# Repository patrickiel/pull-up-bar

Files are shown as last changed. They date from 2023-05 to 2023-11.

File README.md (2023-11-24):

# Pull-up bar

## The idea
An ergonomic pull-up bar for ceiling mounting, which works well in combination with gymnastic rings.

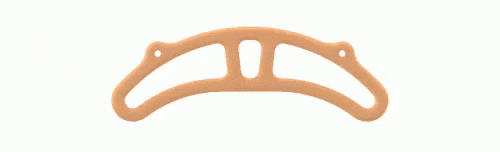
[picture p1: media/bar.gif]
Pullup Bar animation


## Why not buy one?
I decided to build my own pull-up bar because I was not satisfied with the commercially available ceiling mounted pull-up bars. I had the following requirements:
- Ergonomics: Everyone's body is unique. I wanted to create a pull-up bar that fits my body, and yours. You can find a custom drawing that fits your body shape below in the instructions.
- Dismountable: After the workout, the bar should be easy to remove.
- Adjustable grip positions: Narrow, medium and wide grip.
- Resistance Band Friendly: There should be a place to attach a resistance band.
- Minimal damage: Living in a rental apartment, I wanted to minimize damage to the ceiling. The unit hat to be able to mount on the same hooks as the gymnastic rings, which typically have a standard spacing of 50 cm.

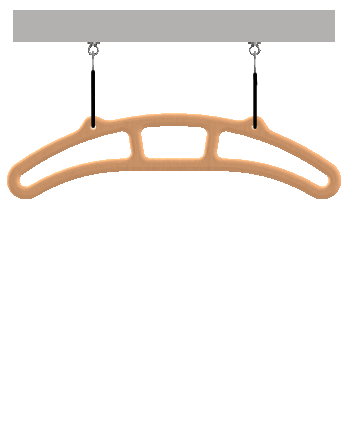
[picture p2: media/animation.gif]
Pull-up bar and rings


## Biacromial breadth
Based on this study https://pubmed.ncbi.nlm.nih.gov/24662157/, the optimal grip width is 1-2 times the biacromial breadth. A medium grip (1.5 times the biacromial width) may have some minor advantages over small and wide grips. This pull-up bar is designed to allow ony grips within this range.

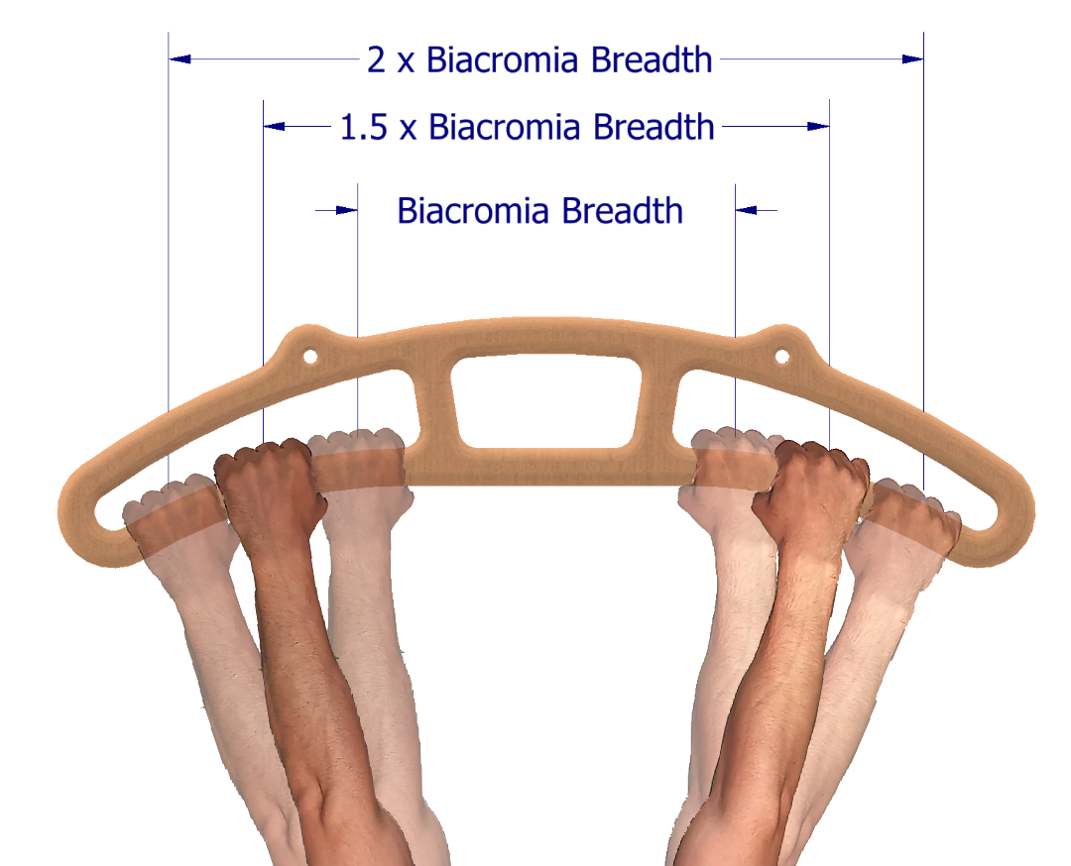
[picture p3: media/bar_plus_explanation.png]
Pull-up bar


# Build instructions

## Choose the plan
Measure your biacromial breadth (search for an online instruction) and choose the corresponding PDF-file [pull-up bar variants](cad/pull-up%20bar%20variants) 

## Tools
- Jigsaw
- Router
- Drill
- Sandpaper
- Tape Measure

## Materials
- Plywood
- Mounting materials (shackles or rope, hooks, carabiners)

## Build it
- If you're using a standard printer, use the tiling feature of your preferred PDF reader to print the second sheet of the PDF on several smaller sheets. Align these using the marks.
- Transfer the outline to the plywood and cut it out.
- Use your router to mill the edges, then sand.
- Mount it to your ceiling.
  
Final build

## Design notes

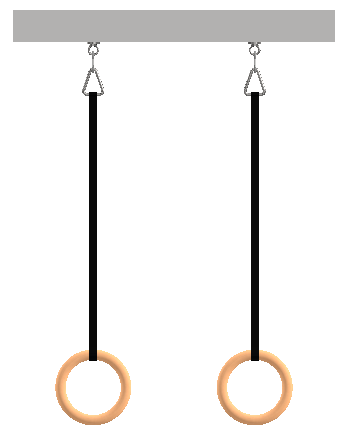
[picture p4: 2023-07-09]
media/animation_2.png

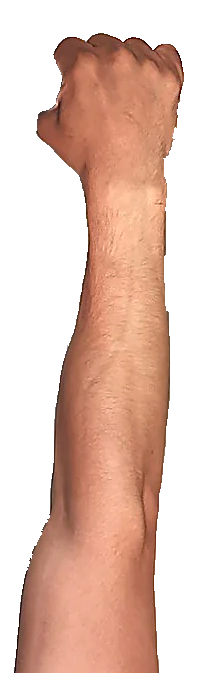
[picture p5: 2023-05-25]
media/right arm.png

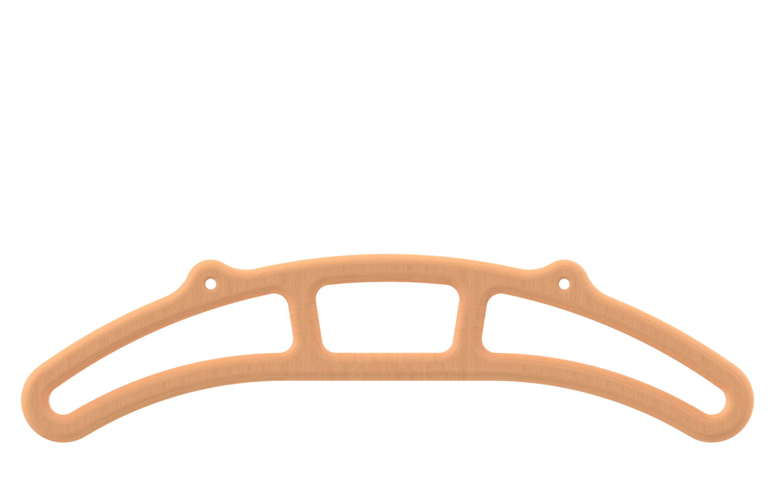
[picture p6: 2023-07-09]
media/bar.png

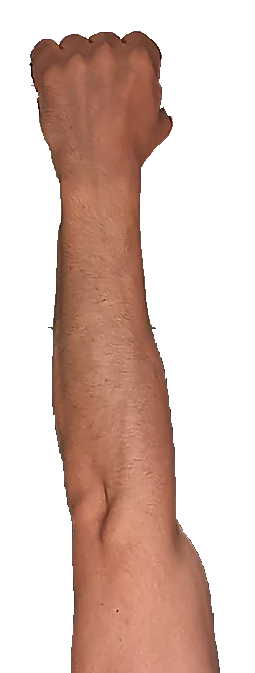
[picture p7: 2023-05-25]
media/left arm.png

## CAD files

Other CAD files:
cad/ISO 4017 - M8 x 50 - ISO.ipt
cad/bar.idw
cad/bar.ipt
cad/carabiner.ipt
cad/ceiling.ipt
cad/ground.ipt
cad/hook.ipt
cad/main.iam
cad/pull-up bar variants/biacromia breadth 25 cm (9.8 inch).idw
cad/pull-up bar variants/biacromia breadth 25 cm (9.8 inch).ipt
cad/pull-up bar variants/biacromia breadth 26 cm (10.2 inch).idw
cad/pull-up bar variants/biacromia breadth 26 cm (10.2 inch).ipt
cad/pull-up bar variants/biacromia breadth 27 cm (10.6 inch).idw
cad/pull-up bar variants/biacromia breadth 27 cm (10.6 inch).ipt
cad/pull-up bar variants/biacromia breadth 28 cm (11 inch).idw
cad/pull-up bar variants/biacromia breadth 28 cm (11 inch).ipt
cad/pull-up bar variants/biacromia breadth 29 cm (11.4 inch).idw
cad/pull-up bar variants/biacromia breadth 29 cm (11.4 inch).ipt
cad/pull-up bar variants/biacromia breadth 30 cm (11.8 inch).idw
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

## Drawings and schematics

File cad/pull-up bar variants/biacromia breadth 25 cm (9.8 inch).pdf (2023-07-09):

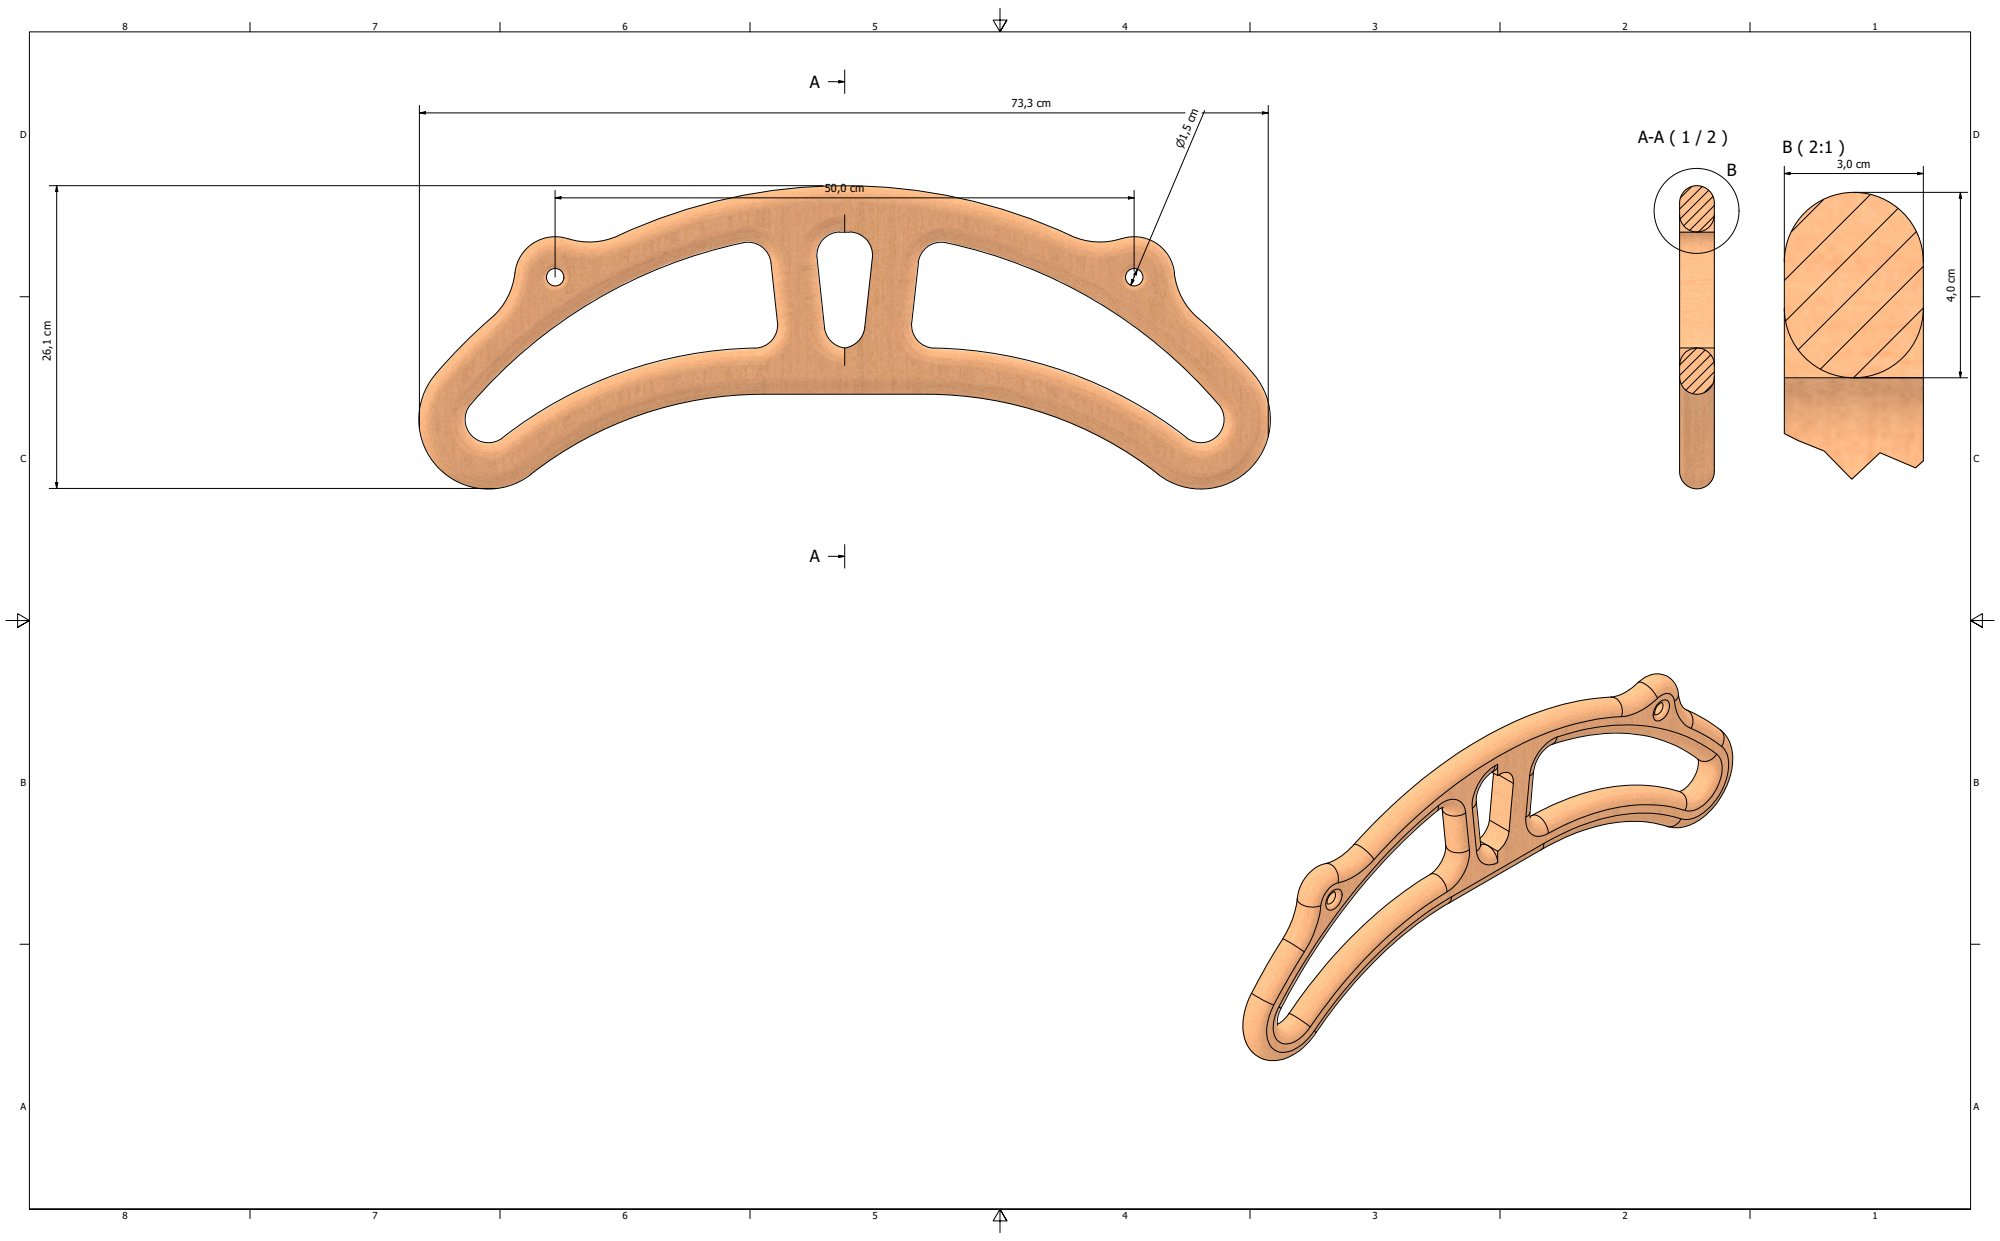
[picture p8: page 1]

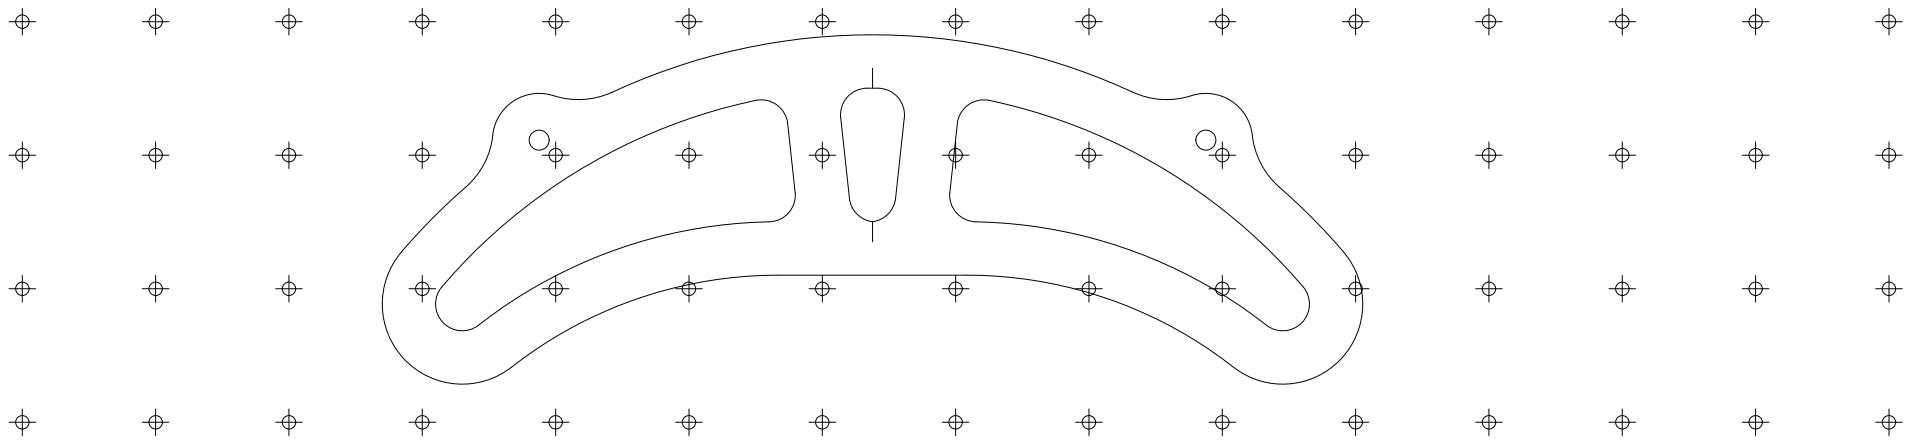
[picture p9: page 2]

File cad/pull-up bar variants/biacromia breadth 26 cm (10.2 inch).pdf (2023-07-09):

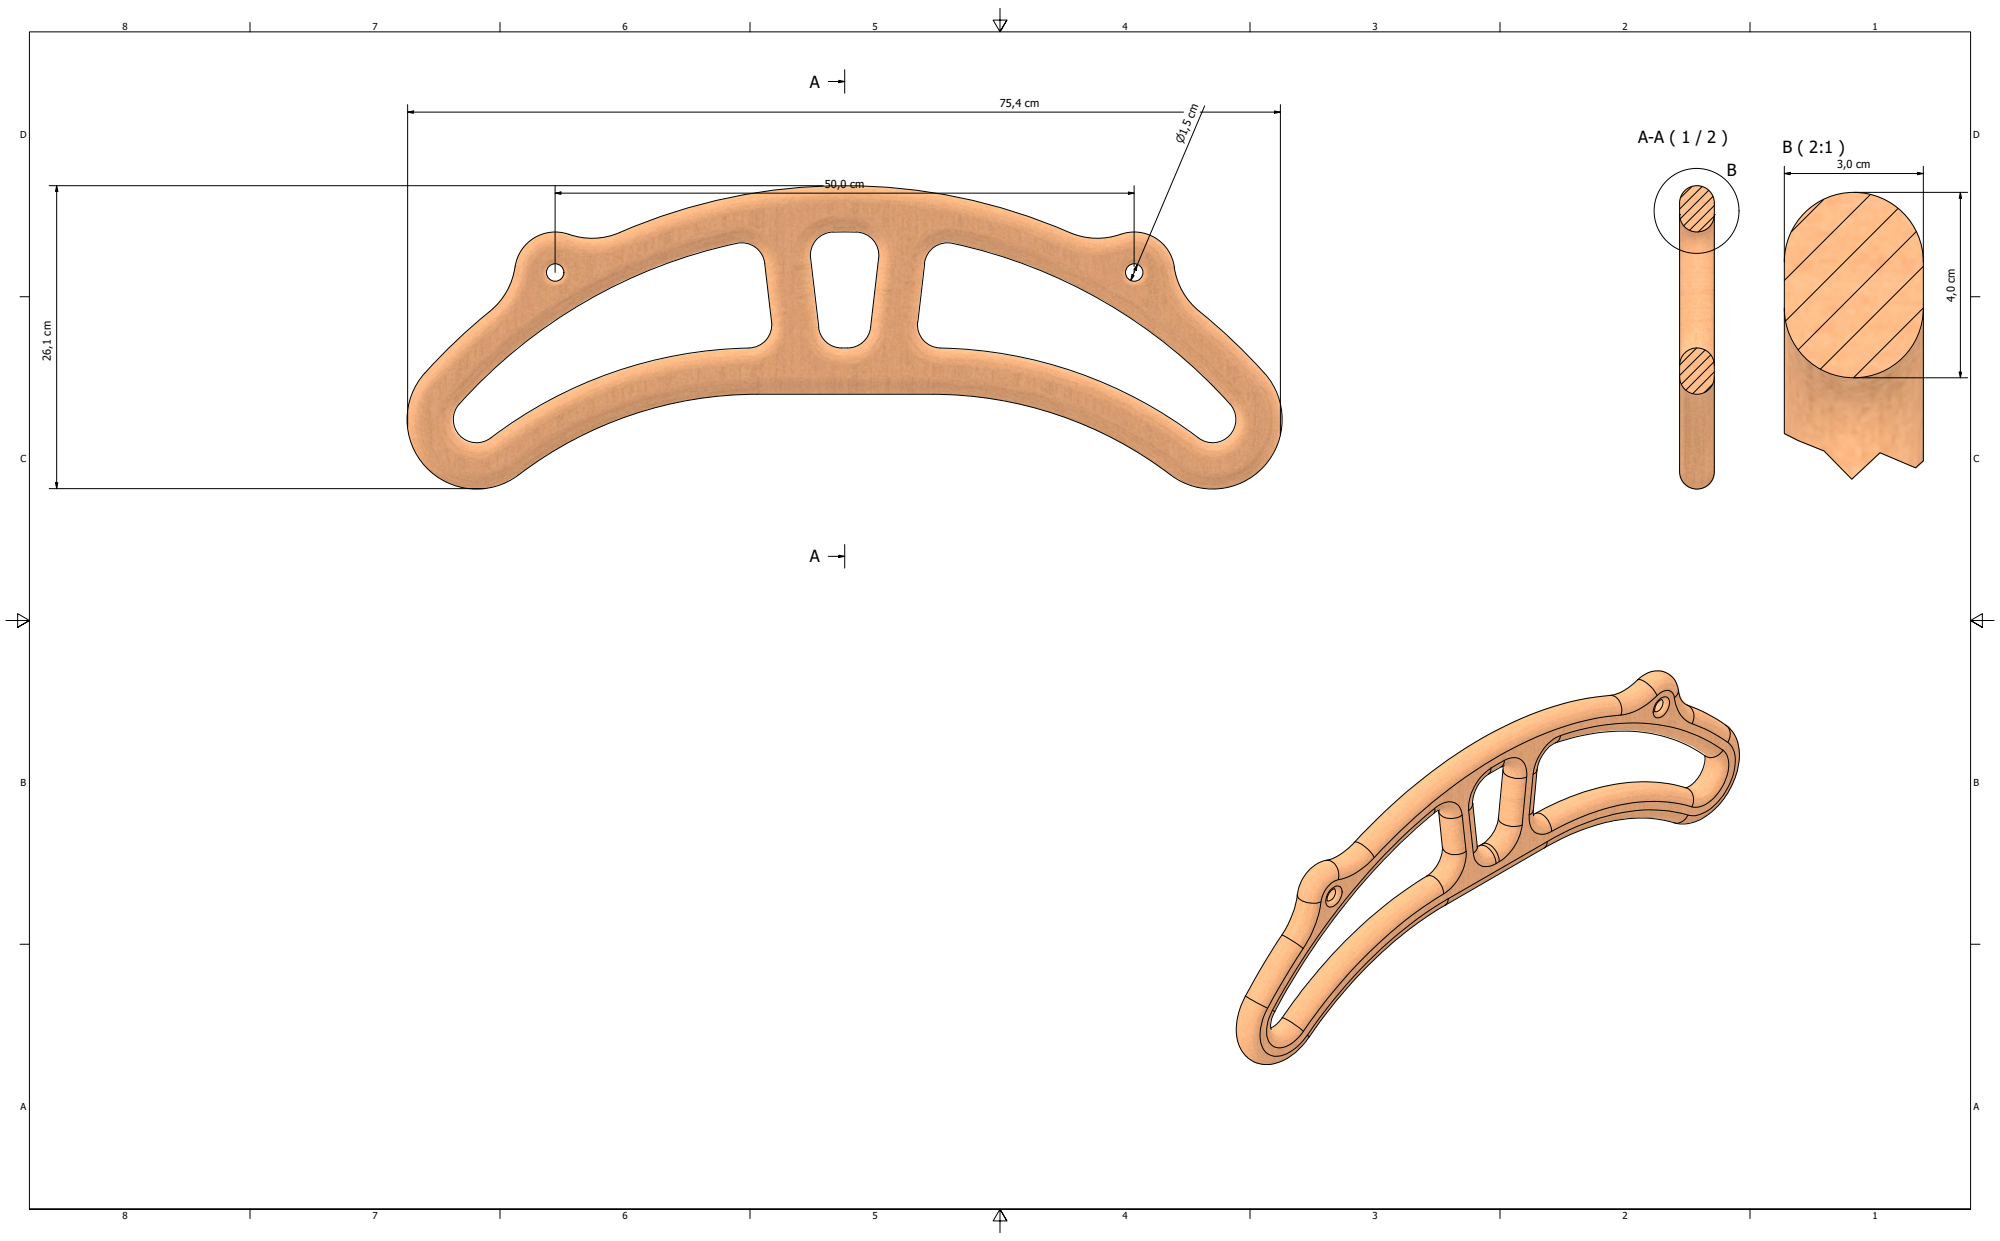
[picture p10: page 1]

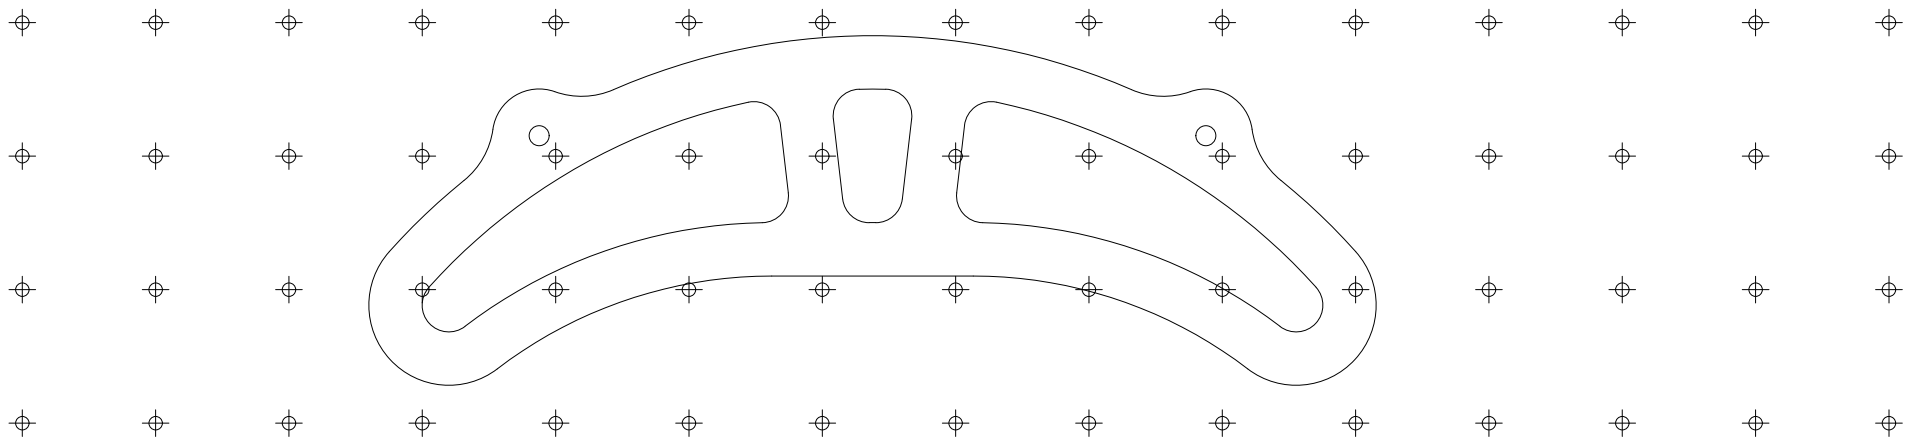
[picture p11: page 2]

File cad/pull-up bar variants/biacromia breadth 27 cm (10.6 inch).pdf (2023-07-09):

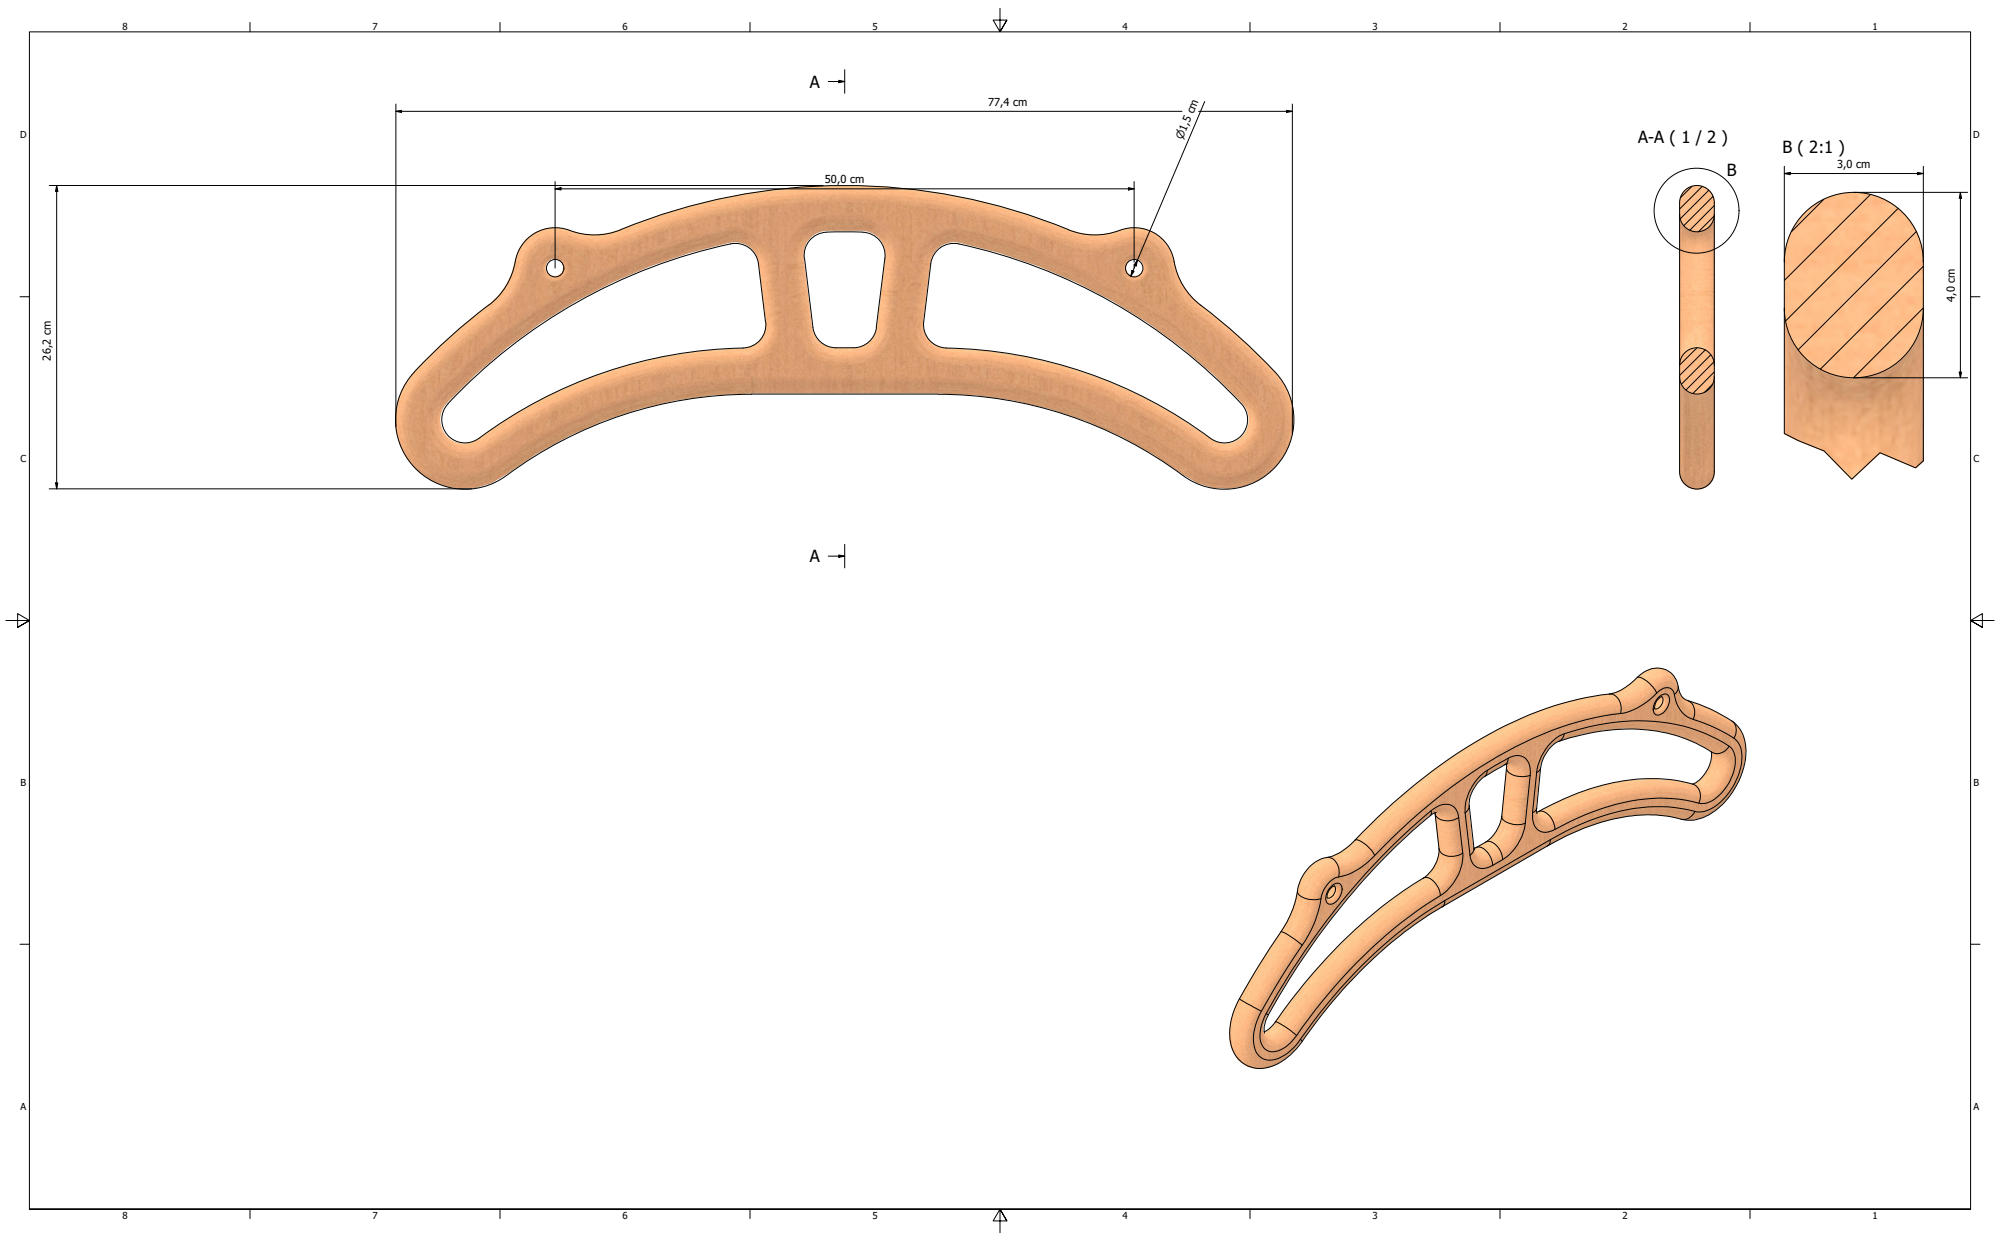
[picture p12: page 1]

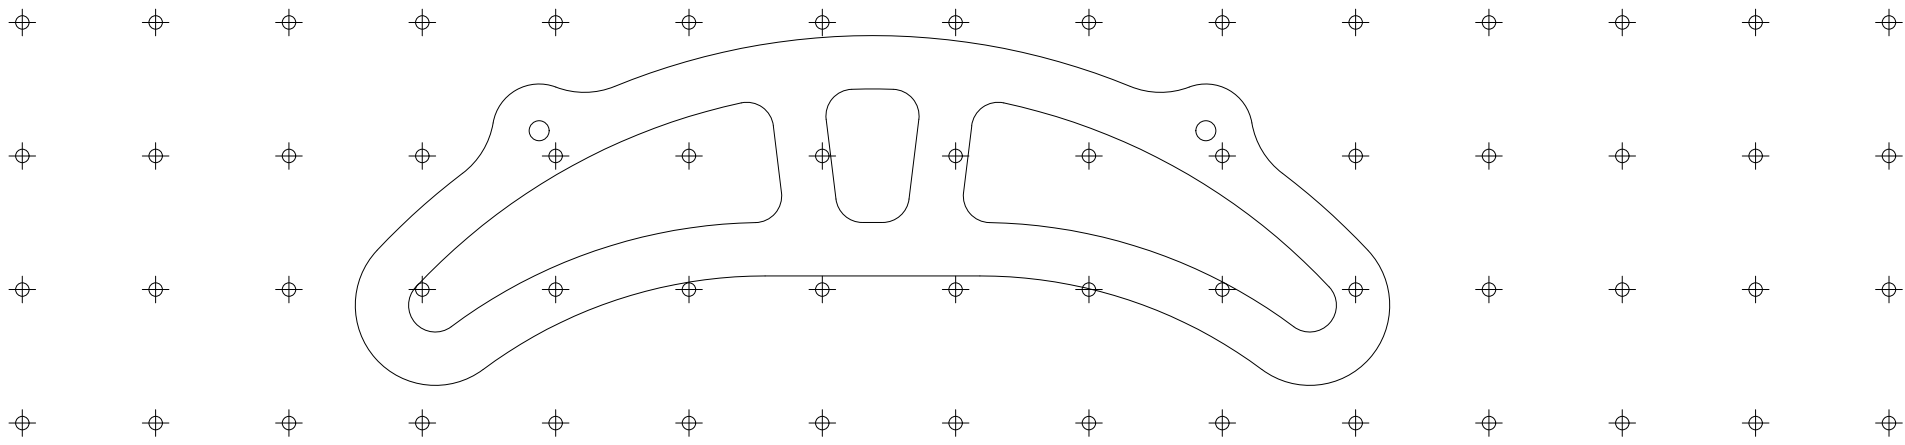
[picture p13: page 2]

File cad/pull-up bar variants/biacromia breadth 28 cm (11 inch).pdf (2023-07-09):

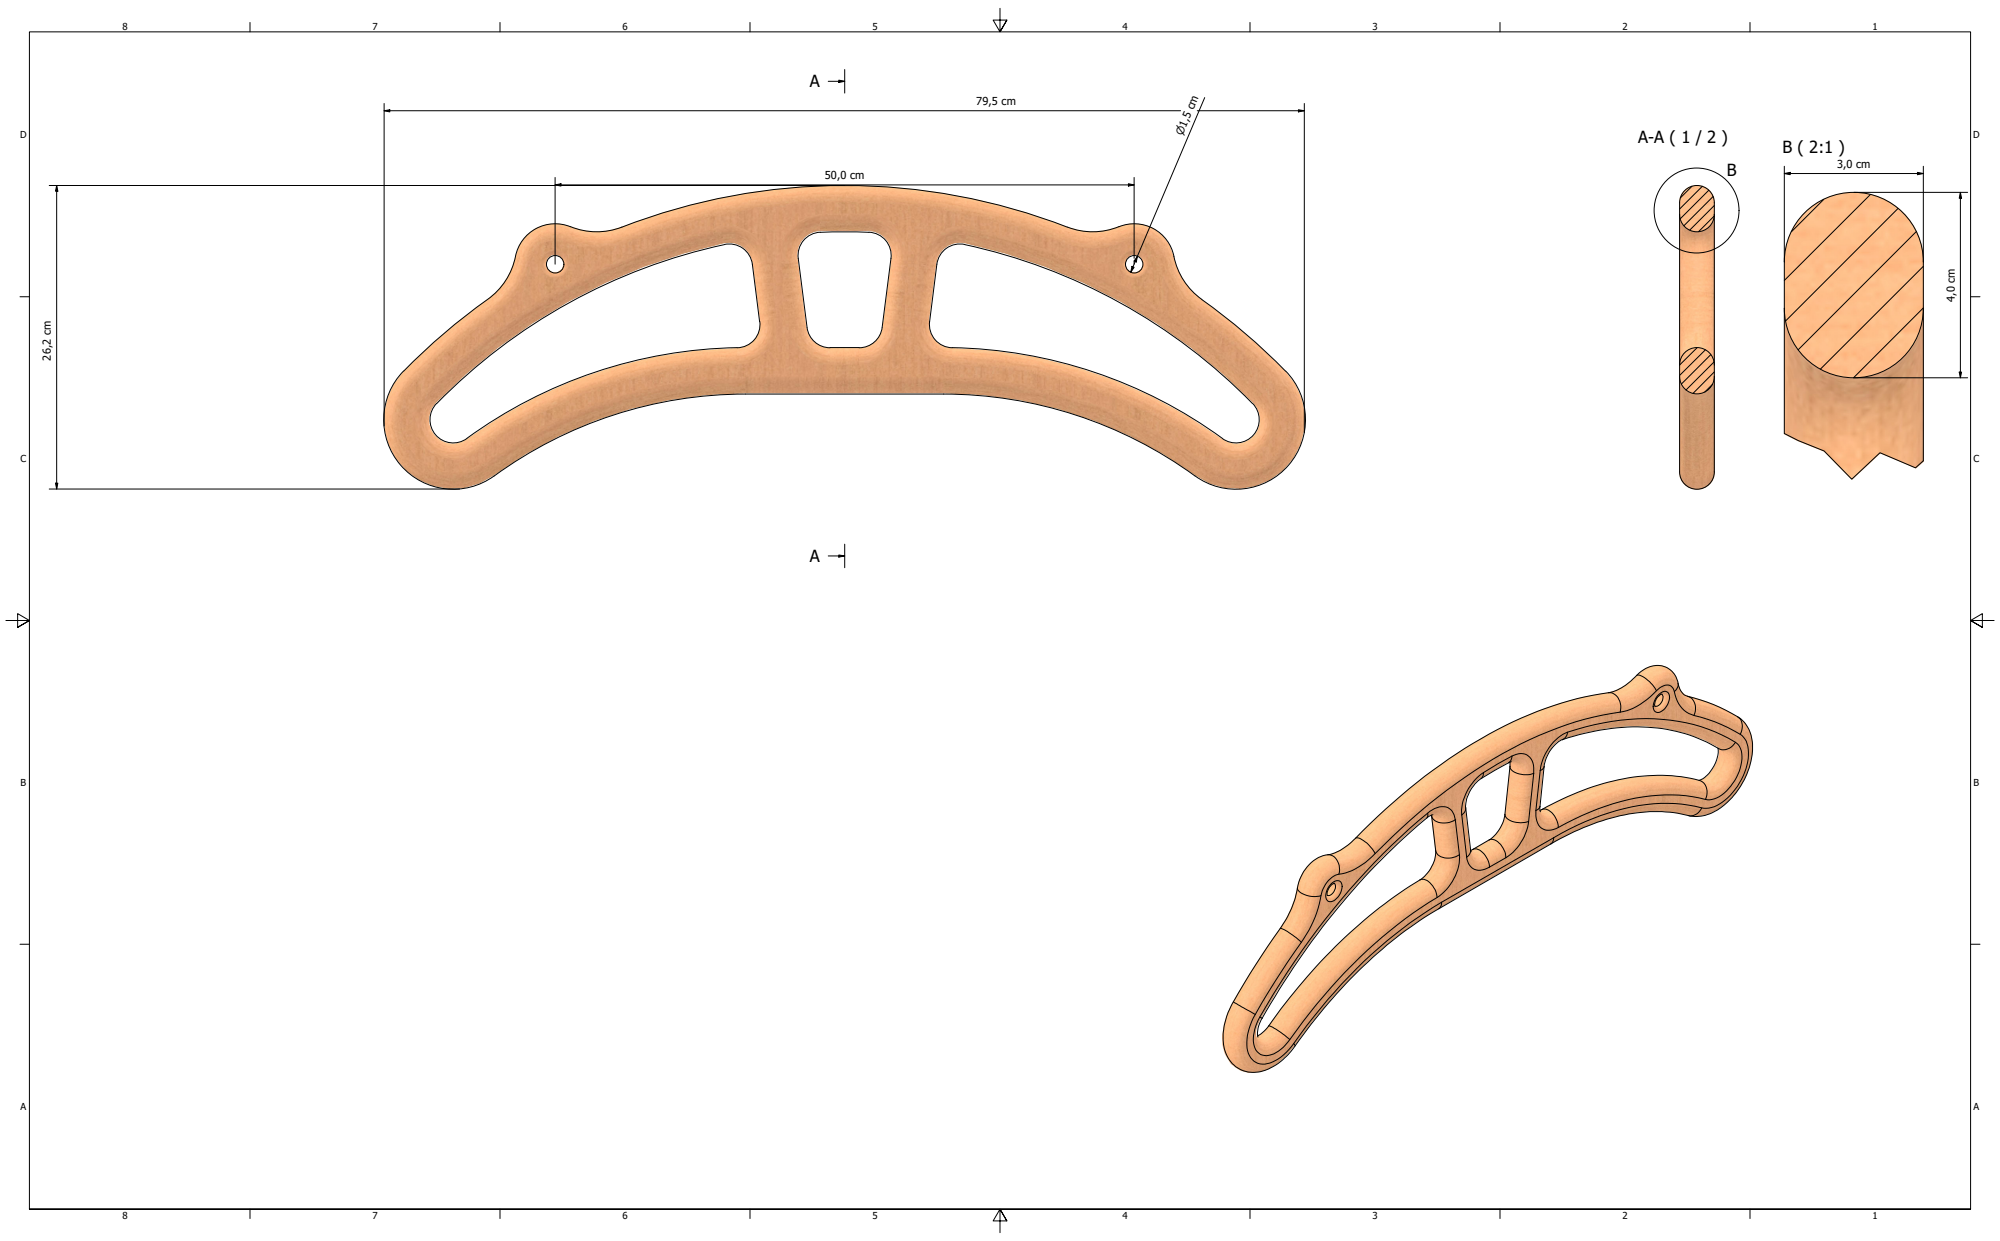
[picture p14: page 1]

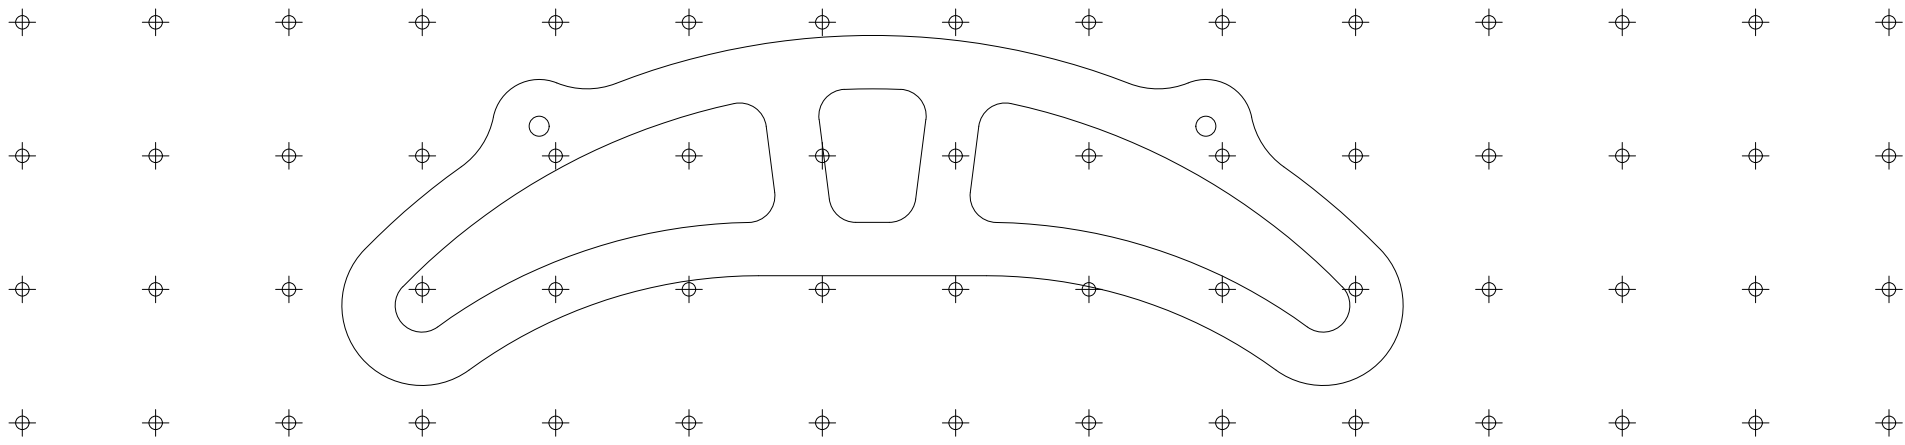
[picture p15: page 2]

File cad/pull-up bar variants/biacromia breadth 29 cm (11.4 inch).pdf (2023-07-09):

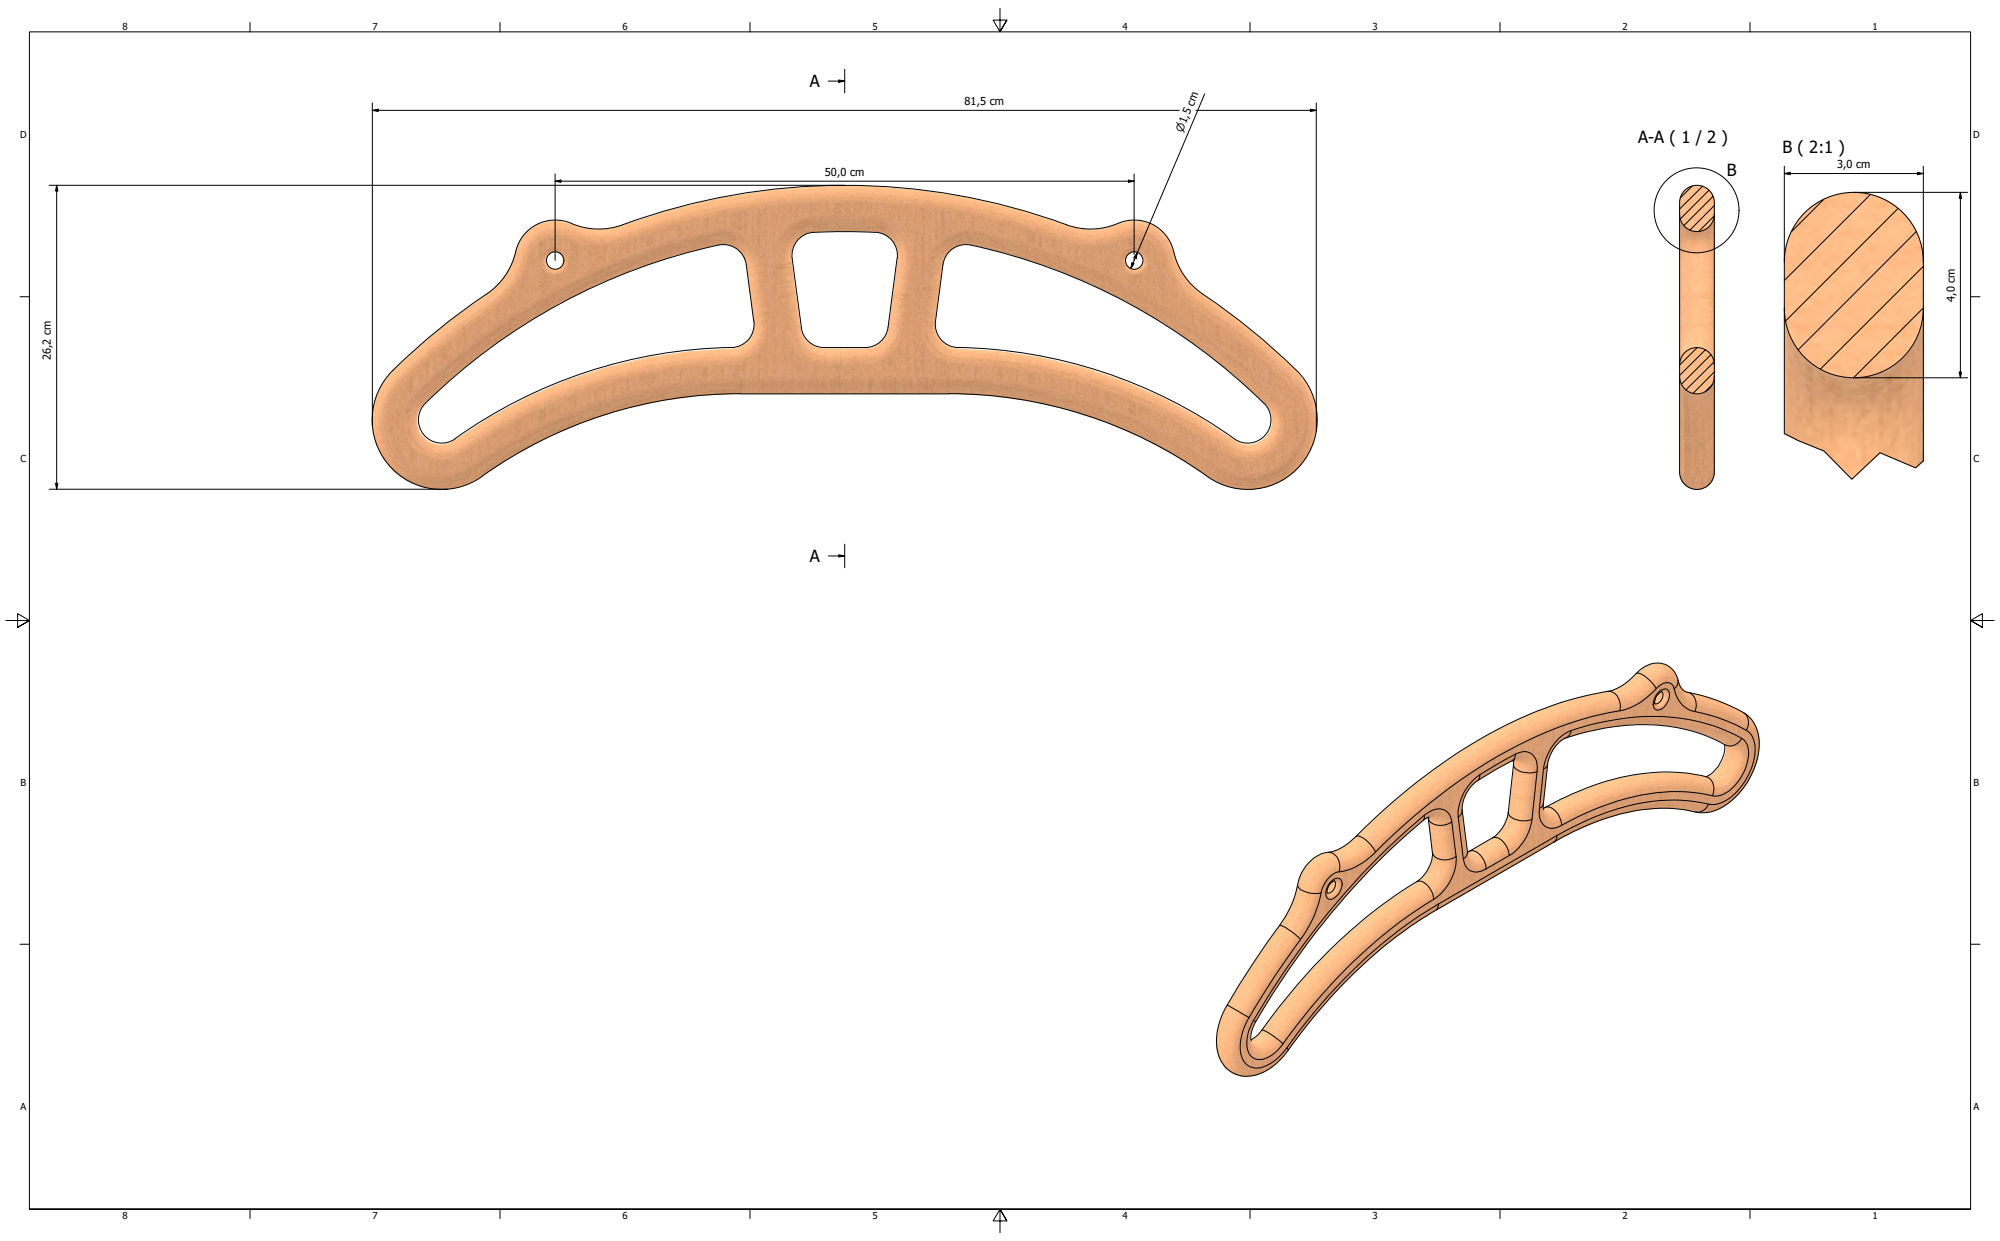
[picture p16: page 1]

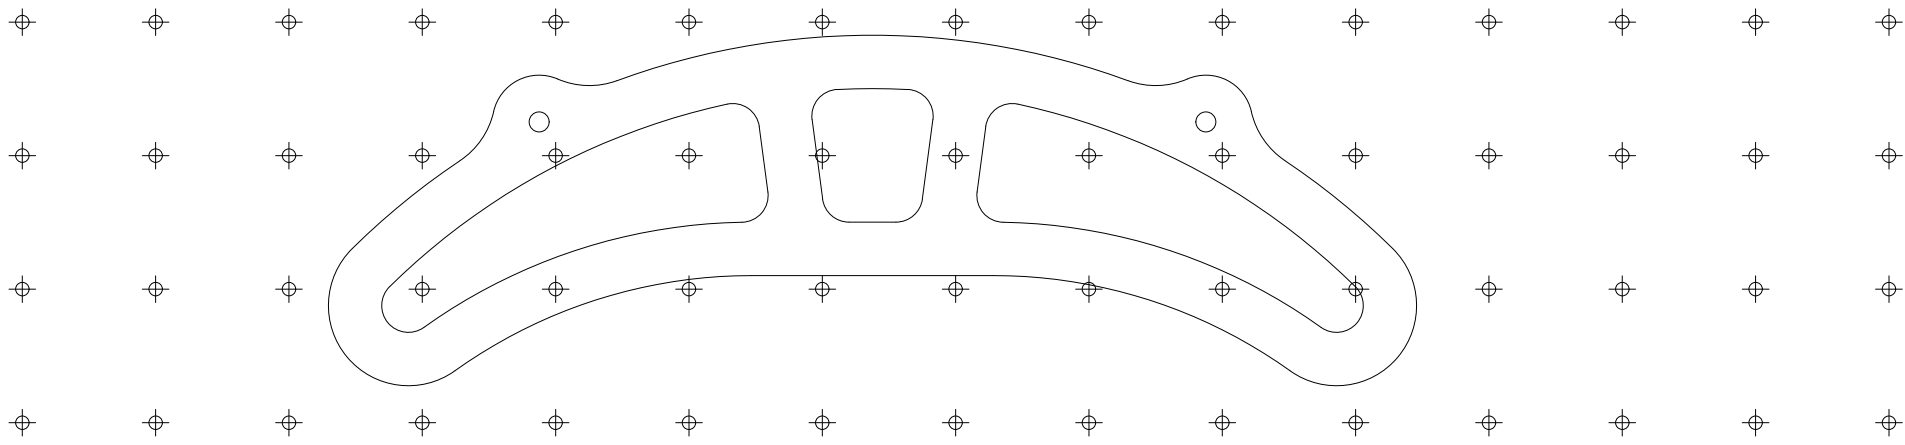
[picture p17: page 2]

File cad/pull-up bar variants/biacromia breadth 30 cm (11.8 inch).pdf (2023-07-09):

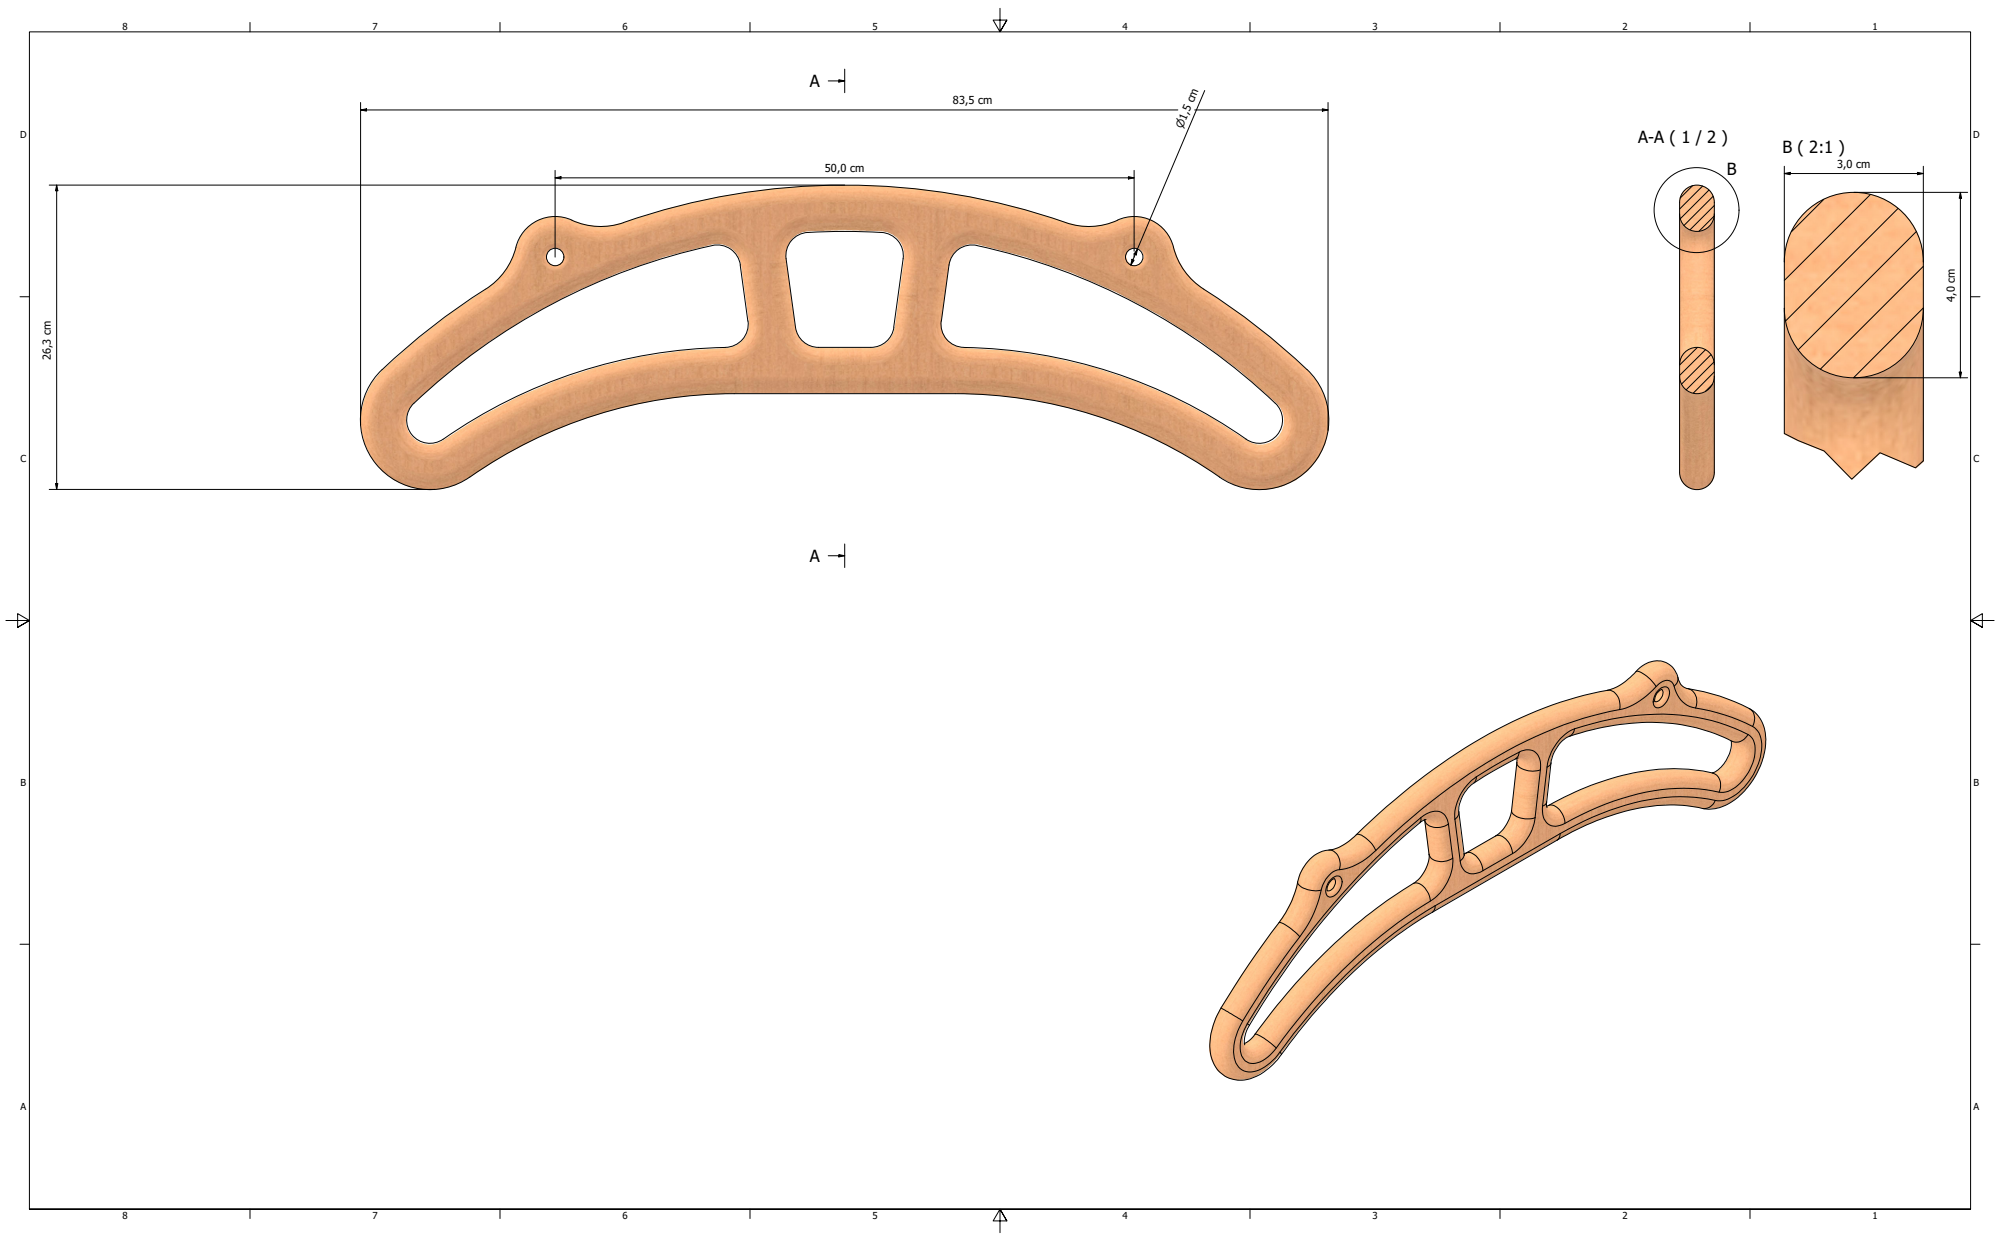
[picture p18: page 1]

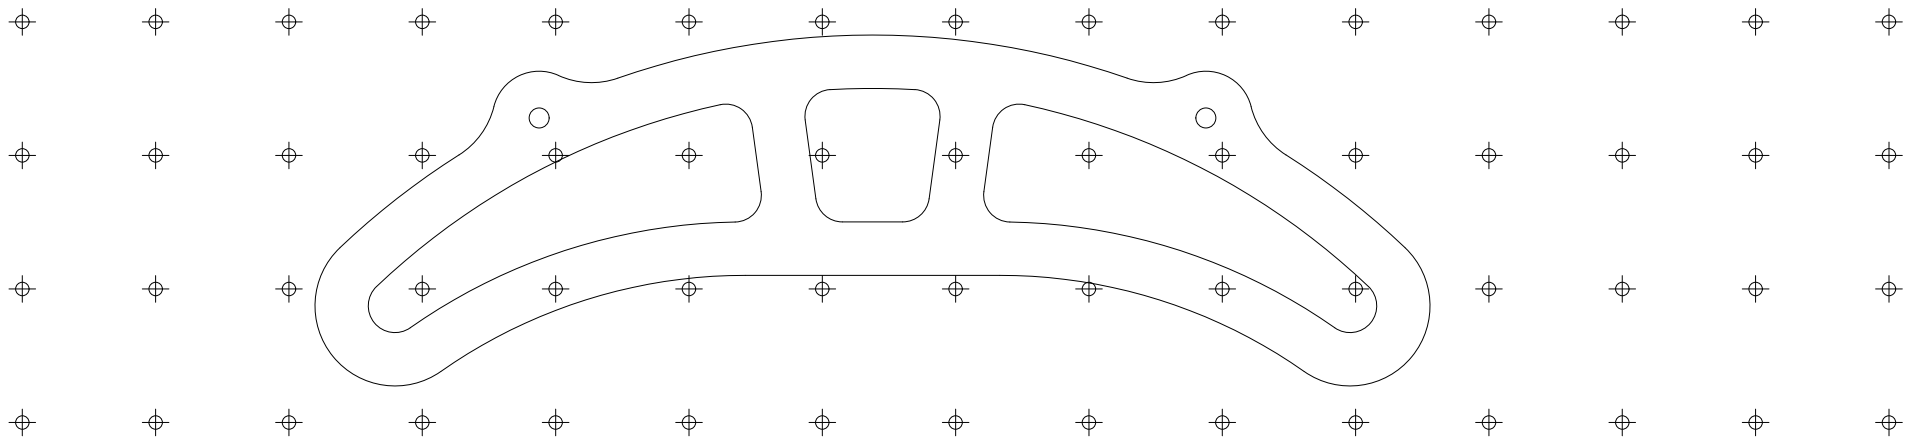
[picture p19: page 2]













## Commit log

2023-05-29 geometry optimized
    [bar.idw, bar.ipt, biacromia breadth 25 cm (9.8 inch).idw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]
2023-05-29 animations added
    [bar.ipt, main.iam]
2023-07-09 minor geometry improvement
    [bar.idw, bar.ipt, biacromia breadth 25 cm (9.8 inch).idw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]
2023-07-09 typo fixed
    [main.iam]
2023-07-09 images updated
    [main.iam]
